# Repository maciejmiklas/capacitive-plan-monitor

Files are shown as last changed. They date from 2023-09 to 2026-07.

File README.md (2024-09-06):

# Capacitive Moisture Monitor based on Atmega 328

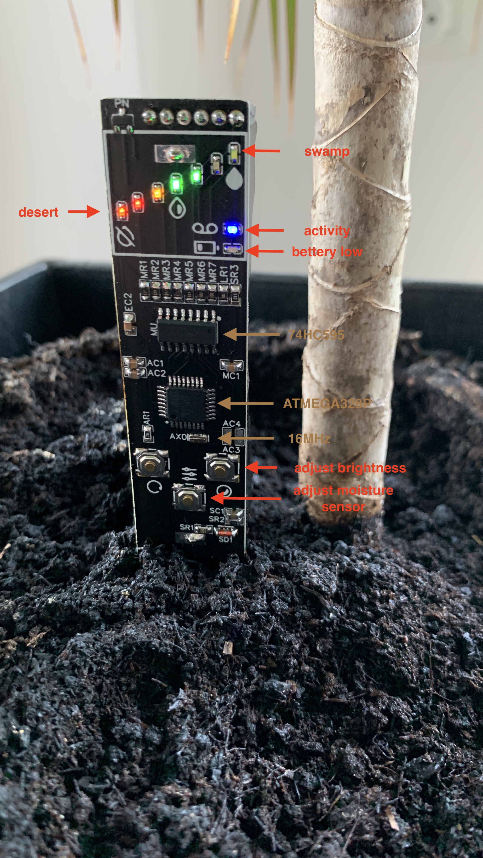
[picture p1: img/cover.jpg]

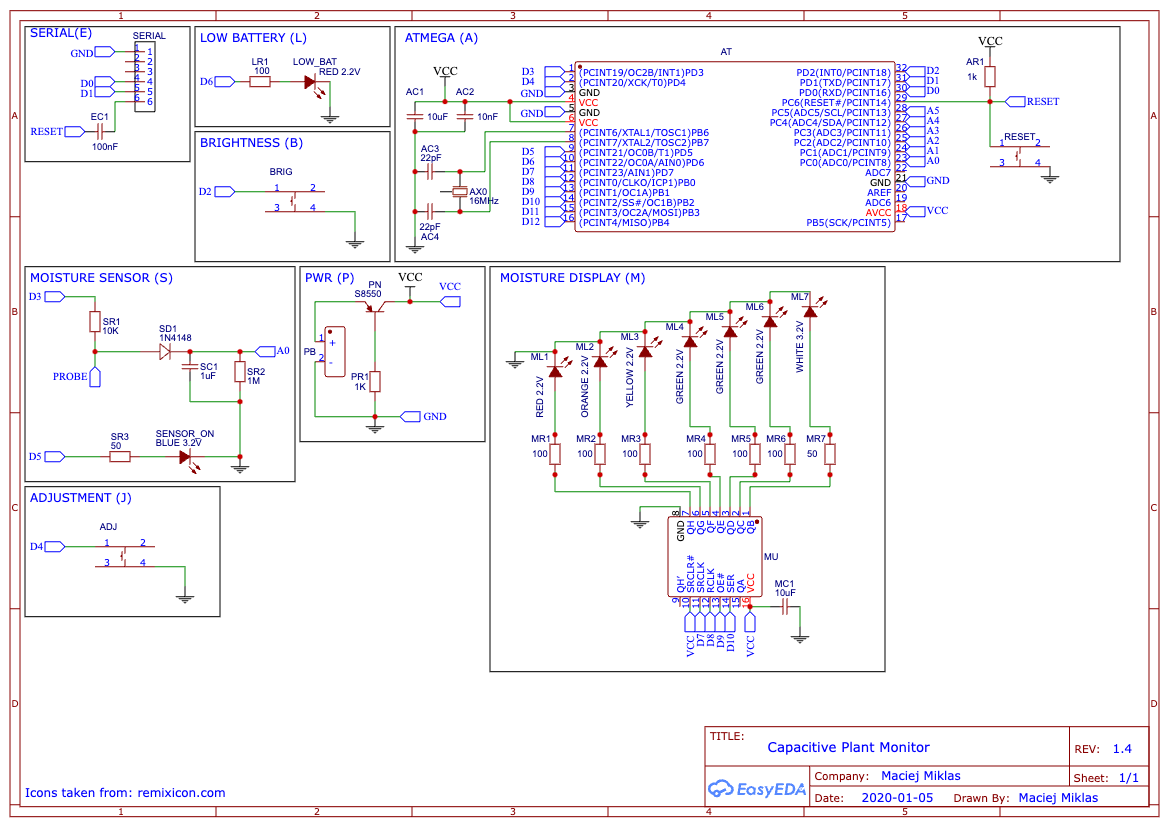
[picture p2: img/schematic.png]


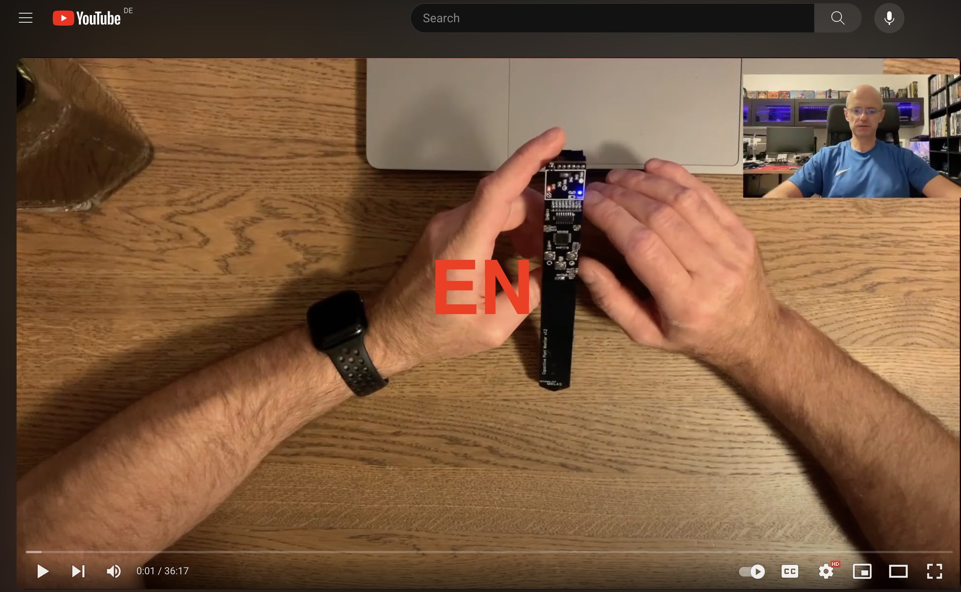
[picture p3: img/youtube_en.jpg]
Youtube EN) (https://youtu.be/DBx7lEarteA)

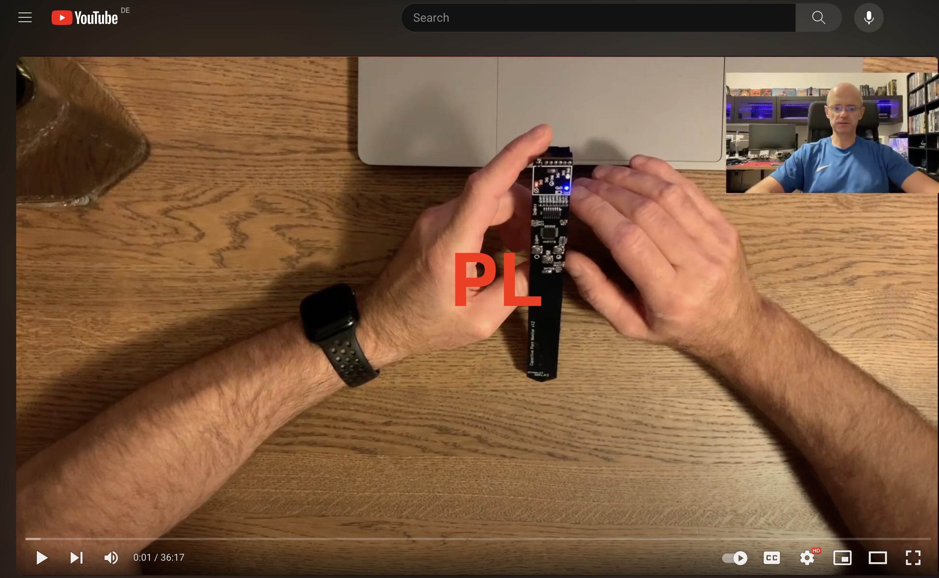
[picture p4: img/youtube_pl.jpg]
Youtube PL) (https://youtu.be/4kX7fkXBnfU)


It runs on a single Lii 3100mAh battery for about two months, depending on the brightness of the LEDs and moisture level. Wet soli lights up more LEDs, resulting in higher power consumption. 

The Atmega runs at 2Mhz to extend battery life; all unnecessary functions are also disabled. It drops power consumption from 30mA to less than 10mA with just a few LEDs enabled on low brightness. Running at 10mA would give us a battery life of about two weeks. To prolong it, Atmega goes to a deep sleep every 2 seconds for 4 seconds. With that trade-off, we should run on a single charge for about two months.

The PCB was designed using EasyEDA: https://oshwlab.com/mac.miklas/capacitive-plant-monitor. It's possible to order PCBs directly from them. Soldering is straightforward, Atmega and 16MHz crystal can be sourced from cheap Arduino boards. Actually, Cristal is unnecessary, as the whole project runs on 2MHz anyway, but that requires an altered bool loader.

To build such a device, you can order PCD directly from EasyEDA and solder standard components up to Atmega and 16MHz Crystal. You can move from those chap Arduino boards. 

The top of the board has a 6-pin header, providing a serial port and reset. It can be directly connected to a USB->seial adapter to program the Atmega. The project can be directly imported into AdruinoIDE (*CapacitivePlantMonitorPrj/CapacitivePlantMonitorPrj.ino*)

We have multiple classes on the software side, each carrying different responsibilities. For Example: 
- *MoistureDisplay* controls LEDs displaying moisture level,
- *MoistureDriver* drives the moisture sensor,
- *PowerSaver* is responsible for deep sleep,
- *VCCMonitor* monitors battery level,
- *BrightnessManager* regulates the brightness 
- and so on...
Classes do not communicate directly. They are decoupled through an Event Bus - this is the most essential part of the software. Each Class can generate Events, process Events, and react to those adequately. All Events can be found in *BusEvent.h* -> this location provides the information about all possible data exchange between software components. For example:
- *MoistureDriver* monitors the moisture level. In the case of a change, it emits the event *MOISTURE_LEVEL_CHANGE*. *MoistureDisplay* receives it and turns on/off LEDs
- the Class *Buttons* handle the buttons. When the adjust button is being pressed, Buttons emit *BTN_ADJ_SENSOR*. Now, there are multiple components interested in this event:
	- *PowerSaver* will postpone deep sleep for 10 seconds as it recognizes the user's interaction, 
	- *ProbeDriver* will stop measurements for a few seconds because those consume CPU cycles, and we are running only at 2MHz,
	- *LED* Class will blink the action LED a few times to give a user feedback that a button press has been recognized

The Class *ArdLog* can be used to enable Logger. It has to be done for each component separately. Log messages go through serial port, and the speed is set to 38400 (*Config#AL_SERIAL_SPEED*), but as we are running at 2Mhz, the serial rate on the PC has to be set to 38400/8=4800

Many things are configurable through *Config.h*, few might be interesting:

``` cpp
// dealy in ms for first standby after power on
const static uint32_t PS_STANDBY_INIT_MS =  20L * 1000L;

// dealy in ms for standby after a button has been pressed
const static uint32_t PS_STANDBY_BUTTON_MS = 20L * 1000L;

// standby frequency during normal operation
const static uint32_t PS_STANDBY_DELAY_MS = 4000L;

// sleep time in seconds during standby
const static SleepPeriod PS_SLEEP = SleepPeriod::S8;
```

It might be necessary to adjust moisture sensor readings:
``` cpp
/**
    Voltage level read from the moisture sensor over input A0 depend on the VCC level, which changes with a battery charge.
    Different battery level reflects the amplitude of generated square wave for a sensor. It is hard to write a function
    that appropriately adjusts readings based on changes in the VCC level because it is not linear. For this reason,
    we are using mapping table for different VCC(batery) levels.
*/
// For calibration set MI_MIN_VCC_CHANGE_MV = 1 and ArdLog -> LOG_MD, LOG to true
const static uint16_t MI_LEVEL_MAP[MI_LEVEL_MAP_SIZE][3] = {
  // {VCC, DRY, WET} (mV)
  { 5000, 3970, 2212 },
  { 4600, 3610, 2000 },
  { 4500, 3530, 1943 },
  { 4400, 3460, 1900 },
  { 4300, 3370, 1840 },
  { 4200, 3300, 1790 },
  { 4100, 3180, 1730 },
  { 4000, 3100, 1680 },
  { 3900, 3010, 1630 },
  { 3800, 2930, 1580 },
  { 3700, 2840, 1530 },
  { 3600, 2770, 1470 },
  { 3500, 2670, 1424 },
  { 3400, 2590, 1370 },
  { 3300, 2490, 1320 },
  { 3200, 2420, 1260 },
  { 3100, 2330, 1200 },
  { 3000, 2330, 1160 },
  { 2000, 2330, 1160 }
};
```

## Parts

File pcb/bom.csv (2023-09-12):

ID | Name | Designator | Footprint | Quantity | Manufacturer Part | Manufacturer | Supplier | Supplier Part | Price | Pins | Contributor | JLCPCB Part Class | Package Display | link
1 | 10uF | AC1,MC1 | C0805 | 2 | CC0805KKX7R9BB105 | YAGEO | LCSC | C91185 | 0.017 | 2 |  | Extended Part
2 | 10nF | AC2 | C0805 | 1 | CC0805KKX7R9BB105 | YAGEO | LCSC | C91185 | 0.017 | 2 |  | Extended Part
3 | 22pF | AC3,AC4 | C0805 | 2 | CC0805KKX7R9BB105 | YAGEO | LCSC | C91185 | 0.017 | 2 |  | Extended Part
4 | Push Button | ADJ,BRIG,RESET | PUSH_BUTTON-SMD_4P | 3 |  |  | Office |  |  | 4 | Smart
5 | 1k | AR1 | R0805 | 1 | WR08X102 JTL | Walsin Tech Corp | LCSC | C384174 | 0.002 | 2 | LCSC |  | No
6 | ATMEGA328P-AU | AT | TQFP-32_L7.0-W7.0-P0.80-LS9.0-BL | 1 | ATMEGA328P-AU | MICROCHIP | LCSC | C14877 | 2.31 | 32 |  | Basic Part
7 | 16MHz | AX0 | OSC-SMD_3P-L3.2-W1.3-P1.2-L | 1 | CSTNE16M0V530000R0 | Murata Electronics | LCSC | C341521 | 0.204 | 3 | LCSC | Extended Part
8 | 100nF | EC1 | C0805 | 1 | CC0805KKX7R9BB105 | YAGEO | LCSC | C91185 | 0.017 | 2 |  | Extended Part
9 | RED 2.2V | LOW_BAT,ML1 | LED0603-RD | 2 | FC-1608YOXK-600H08 | NATIONSTAR | LCSC | C108553 | 0.022 | 2 | LCSC | Extended Part
10 | 100 | LR1,MR1,MR2,MR3,MR4,MR5,MR6 | R0805 | 7 | WR08X102 JTL | Walsin Tech Corp | LCSC | C384174 | 0.002 | 2 | LCSC |  | No
11 | ORANGE 2.2V | ML2 | LED0603-RD | 1 | FC-1608YOXK-600H08 | NATIONSTAR | LCSC | C108553 | 0.022 | 2 | LCSC | Extended Part
12 | YELLOW 2.2V | ML3 | LED0603-RD | 1 | FC-1608YOXK-600H08 | NATIONSTAR | LCSC | C108553 | 0.022 | 2 | LCSC | Extended Part
13 | GREEN 2.2V | ML4,ML5,ML6 | LED0603-RD | 3 | FC-1608YOXK-600H08 | NATIONSTAR | LCSC | C108553 | 0.022 | 2 | LCSC | Extended Part
14 | WHITE 3.2V | ML7 | LED0603-RD | 1 | FC-1608YOXK-600H08 | NATIONSTAR | LCSC | C108553 | 0.022 | 2 | LCSC | Extended Part
15 | 50 | MR7,SR3 | R0805 | 2 | WR08X102 JTL | Walsin Tech Corp | LCSC | C384174 | 0.002 | 2 | LCSC |  | No
16 | CD74HC595M96 | MU | SOIC-16_L10.8-W4.5-P1.27-LS6.8-BL | 1 | CD74HC595M96 | TI | LCSC | C131977 | 0.582 | 16 |  | Extended Part
17 | ‎BK-18650-PC2‎ | PB | 18650_BAT_MM | 1 | BK-18650-PC2 | MPD (Memory Protection Devices) | Digi-Key | BK-18650-PC2-ND |  | 2 | crojasq |  | No
18 | S8550 | PN | SOT-23-3_L2.9-W1.3-P1.90-LS2.4-BR | 1 | S8550 | CBI(创基) | LCSC | C2828467 | 0.009 | 3 | LCSC
19 | 1K | PR1 | R0805 | 1 | WR08X102 JTL | Walsin Tech Corp | LCSC | C384174 | 0.002 | 2 | LCSC |  | No
20 | 1uF | SC1 | C0805 | 1 | CC0805KKX7R9BB105 | YAGEO | LCSC | C91185 | 0.017 | 2 |  | Extended Part
21 | 1N4148 | SD1 | SOD-123FL_L2.6-W1.6-LS3.4-R-FD | 1 | 1N4148W | Tak Cheong | LCSC | C129216 | 0.02 | 2 | LCSC | Extended Part
22 | BLUE 3.2V | SENSOR_ON | LED0603-RD | 1 | FC-1608YOXK-600H08 | NATIONSTAR | LCSC | C108553 | 0.022 | 2 | LCSC | Extended Part
23 | SERIAL | SERIAL | 2.54 6PIN | 1 |  |  |  |  |  | 6 | fifi1231231
24 | 10K | SR1 | R0805 | 1 | WR08X102 JTL | Walsin Tech Corp | LCSC | C384174 | 0.002 | 2 | LCSC |  | No
25 | 1M | SR2 | R0805 | 1 | WR08X102 JTL | Walsin Tech Corp | LCSC | C384174 | 0.002 | 2 | LCSC |  | No

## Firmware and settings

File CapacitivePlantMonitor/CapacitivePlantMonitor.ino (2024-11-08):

/*
 * Licensed to the Apache Software Foundation (ASF) under one or more
 * contributor license agreements.  See the NOTICE file distributed with
 * this work for additional information regarding copyright ownership.
 * The ASF licenses this file to You under the Apache License, Version 2.0
 * (the "License"); you may not use this file except in compliance with
 * the License.  You may obtain a copy of the License at
 *
 *      http://www.apache.org/licenses/LICENSE-2.0
 *
 * Unless required by applicable law or agreed to in writing, software
 * distributed under the License is distributed on an "AS IS" BASIS,
 * WITHOUT WARRANTIES OR CONDITIONS OF ANY KIND, either express or implied.
 * See the License for the specific language governing permissions and
 * limitations under the License.
 */
#include "ArdLog.h"
#include "Util.h"
#include "MoistureSensor.h"
#include "MoistureDisplay.h"
#include "MoistureDriver.h"
#include "Arduino.h"
#include "EventBus.h"
#include "LED.h"
#include "Buttons.h"
#include "BrightnessManager.h"
#include "VCCMonitor.h"
#include "PowerSaver.h"
#include "ProbeDriver.h"

LED* led = new LED();
BrightnessManager* brManager = new BrightnessManager();
Buttons* buttons = new Buttons();
PowerSaver* ps = new PowerSaver();
MoistureDisplay* mi = new MoistureDisplay();
ProbeDriver* pd = new ProbeDriver();
VCCMonitor* pm = new VCCMonitor();
MoistureSensor* ms = new MoistureSensor();
MoistureDriver* md = new MoistureDriver(ms, pm);

const static uint8_t DEVICES = 9;
Device* dev[DEVICES] = { led, brManager, buttons, ps, mi, pd, pm, ms, md };

const static uint8_t DEMOS = 2;
Demo* demos[DEMOS] = { led, mi };

/** ### SETUP ### */
void setup() {
#if LOG
  log_setup();
#endif

#if LOG && LOG_CPM
  log(F("\n\n### SETUP ###"));
#endif
  util_setup();
  util_cycle();

  execSetup();
  execDemo();
  execDemosDone();

  clock_prescale_set(CP_CLOCK_DIV);
}

/** ### LOOP ### */
void loop() {
#if LOG && LOG_CPM
  log(F("### LOOP ###"));
#endif

  util_cycle();

  eb_fire(BusEvent::CYCLE);

  if (CP_LOOP_DELAY > 0) {
    delay(CP_LOOP_DELAY);
  }
}

void execDemo() {
  for (uint8_t i = 0; i < DEMOS; i++) {
    demos[i]->demo();
  }
}


void execDemosDone() {
  for (uint8_t i = 0; i < DEMOS; i++) {
    demos[i]->demosDone();
  }
}

void execSetup() {
  for (uint8_t i = 0; i < DEVICES; i++) {
    dev[i]->setup();
  }
}

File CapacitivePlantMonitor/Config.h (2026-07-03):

/*
   Licensed to the Apache Software Foundation (ASF) under one or more
   contributor license agreements.  See the NOTICE file distributed with
   this work for additional information regarding copyright ownership.
   The ASF licenses this file to You under the Apache License, Version 2.0
   (the "License"); you may not use this file except in compliance with
   the License.  You may obtain a copy of the License at

        http://www.apache.org/licenses/LICENSE-2.0

   Unless required by applicable law or agreed to in writing, software
   distributed under the License is distributed on an "AS IS" BASIS,
   WITHOUT WARRANTIES OR CONDITIONS OF ANY KIND, either express or implied.
   See the License for the specific language governing permissions and
   limitations under the License.
*/
#ifndef CONFIG_H
#define CONFIG_H

#include <Arduino.h>
#include <avr/power.h>

// ####### CapactitvePlantMonitorPrj(CP) ######
const static uint16_t CP_LOOP_DELAY = 0;
const static uint16_t CP_DEMO_DELAY_MS = 500;
const static clock_div_t CP_CLOCK_DIV = clock_div_8;  // make sure that CP_CLOCK_DIV_INT has correcponding value!
const static uint8_t CP_CLOCK_DIV_INT = 8;

// ######## DIGITAL PINs ########
// PWM PINs: 3, 5, 6, 9, 10, 11
const static uint8_t D1 = 1;
const static uint8_t D2 = 2;      // BT_PIN_BRIGHTNESS
const static uint8_t D3_PWM = 3;  // MS_PIN_PWM_OUT, MoistureSensor sets Timer 2 for 200MHz on PIN 3 and 11
const static uint8_t D4 = 4;      // BT_PIN_MI_ADJUST
const static uint8_t D5_PWM = 5;  // LE_PIN_SENSOR_ON
const static uint8_t D6_PWM = 6;  // LE_PIN_PWR_LOW
const static uint8_t D7 = 7;      // MI_PIN_CLOCK
const static uint8_t D8 = 8;      // MI_PIN_LATCH
const static uint8_t D9_PWM = 9;  // MI_PIN_ENABLE
const static uint8_t D10 = 10;    // MI_PIN_DATA
const static uint8_t D11 = 11;
const static uint8_t D12 = 12;

// ######## ArdLog(AL) ########
/**
   The clock is set to 2MHz (CP_CLOCL_DIV = clock_div_8) using a divider of 8.
   The serial is set to 38400, but due to the divider, it gives an actual speed of 4800 because 38400/8=4800.
   However, in order to see initial logs set serial to 38400, because prescaller is set after system initialization.
*/
// ### Serial works at 4800 due to clock prescaler! ###
const static uint32_t AL_SERIAL_SPEED = 38400;

/** Buffer size for sprintf-template passed as first argument to log method. */
const static uint8_t AL_PGBUF_SIZE = 64;

/** Buffer size for created message. */
const static uint8_t AL_SBUF_SIZE = 96;

// ######## BUTTONS(BT) ########
const static uint8_t BT_PIN_BRIGHTNESS = D2;
const static uint8_t BT_PIN_MI_ADJUST = D4;
const static uint8_t BT_PRESS_MS = 20;

// ######## MOISTURE SENSOR(MS) ########
const static uint8_t MS_PIN_PWM_OUT = D3_PWM;
const static uint8_t MS_PIN_READ = A0;

/** Clock 2MHz (16/8=2) -> PWM at 200kHz, 30% duty */
const static uint8_t MS_PWM_PERIOD = 9;
const static uint8_t MS_PWM_DUTY = 4;

// ######## LED(LE) ########
const static uint8_t LE_PIN_AWAKE = D5_PWM;
const static uint8_t LE_PIN_PWR_LOW = D6_PWM;
const static uint16_t LE_DEMO_DELAY = 100;
const static uint16_t LE_DEMO_BLNIKS = 3;
const static uint16_t LE_PWM_HZ = 100;

const static uint8_t LE_PRESS_BLINK_REPEAT = 3;
const static uint8_t LE_PRESS_BLINK_ON_DELAY = 3;
const static uint8_t LE_PRESS_BLINK_OFF_DELAY = 6;

const static uint8_t LED_BR_MAX_BLINK_REPEAT = 6;
const static uint8_t LED_BR_MAX_BLINK_ON_DELAY = 3;
const static uint8_t LED_BR_MAX_BLINK_OFF_DELAY = 6;

const static uint8_t LE_PWR_LOW_ON_DELAY = 100;
const static uint8_t LE_PWR_LOW_ON_BRIGHTNESS = 100;
const static uint8_t LE_PWR_LOW_OFF_DELAY = 50;
const static uint8_t LE_PWR_LOW_OFF_BRIGHTNESS = 5;

// ######## BrightnessManager(BM) ########
const static uint8_t BM_BRIGHTNESS_OFF = 0;
const static uint8_t BM_BRIGHTNESS_MIN = 1;
const static uint8_t BM_BRIGHTNESS_MAX = 255;
const static uint8_t BM_BRIGHTNESS_CHANGE = 10;
const static uint8_t BM_BRIGHTNESS_INITIAL = 1;

// ######## ProbeDriver(PD)  ########
// stop probing for given time after user interaction, like button press
const static uint32_t PD_PROBE_SUSPEND_BUTTON_MS = 2000;
const static uint32_t PD_PROBE_SUSPEND_STANDBY_MS = 10;
const static uint32_t PD_FREQ_MS = 200;

// ######## MoistureDisplay(MI) ########

/** PIN 11 (SRCLK) on 74HC595 */
const static uint8_t MI_PIN_CLOCK = D7;

/** PIN 12 (RCLK) on 74HC595 */
const static uint8_t MI_PIN_LATCH = D8;

/** PIN 13 (OE) on 74HC595 */
const static uint8_t MI_PIN_ENABLE = D9_PWM;

/** PIN 14 (SER) on 74HC595 */
const static uint8_t MI_PIN_DATA = D10;

const static uint8_t MI_DEMO_DELAY = 50;
const static uint8_t MI_DEMO_MIDDLE_DELAY = 200;

/** Level that will disable all LEDs. */
const static uint8_t MI_LEVEL_OFF = 0;

/** Min level inclusive. */
const static uint8_t MI_LEVEL_MIN = 1;

/** Max level inclusive. */
const static uint8_t MI_LEVEL_MAX = 7;
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

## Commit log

2023-02-02 starting power saving functions
2023-03-18 before switching to Message Bus
2023-05-06 power saver working
2023-05-30 low power blink in dev
